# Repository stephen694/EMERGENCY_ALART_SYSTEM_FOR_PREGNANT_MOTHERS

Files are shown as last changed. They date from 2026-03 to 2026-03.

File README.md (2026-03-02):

 Julius-branch
# Emergency Alert System for Pregnant Mothers in Kenya

> *Saving Lives with One Button — Fast, Simple, Reliable Maternal Emergency Alerts*

# Quick Links

- [Project Report (Final)](./Emergency_Alert_System_Final_Report.docx)
- [Circuit Schematic (Fritzing / EasyEDA)](./doc/schematic/)
- [Firmware Source Code](./src/)
- [Deployment & Field Testing Notes](./doc/deployment.md)

# Emergency Alert System on Arduino

This project brings a one-button maternal emergency alert device to life using the Arduino Uno platform. It allows a pregnant woman — with no smartphone, no internet, and no need to speak — to dispatch an SMS alert containing her real-time GPS location to pre-registered healthcare contacts with a single button press.

The system leverages Kenya's existing GSM mobile network infrastructure (Safaricom, Airtel, Telkom) and is designed to complement the [m-mama](https://www.mobilematernityafrica.org/) emergency transport system. Its low-power design supports both USB and solar charging, making it suitable for off-grid rural Kenyan communities.

# Contents

- Installation & Setup:
  - [Hardware Assembly](#hardware-assembly)
  - [Uploading Firmware via Arduino IDE](#uploading-firmware-via-arduino-ide)
  - [Configuring Emergency Contacts](#configuring-emergency-contacts)
  - [Power Options](#power-options)
- [How It Works](#how-it-works)
- [System Architecture](#system-architecture)
- [Components & Libraries](#components--libraries)
- [Documentation](#documentation)
- [Issues and Support](#issues-and-support)
- [Contributing](#contributing)
- [License and Credits](#license-and-credits)

---

## Hardware Assembly

The following components are required to assemble the device:

| Component | Specification |
|---|---|
| Microcontroller | Arduino Uno |
| GSM Module | SIM800L or SIM900 |
| GPS Module | Neo-6M |
| Display | 16x2 LCD |
| User Input | Physical Push Button |
| Audio Feedback | 5V Buzzer |
| Power | USB or Solar-compatible stable supply |

Refer to the circuit schematic in [`/doc/schematic/`](./doc/schematic/) for wiring diagrams produced in Fritzing and EasyEDA.

1. Wire the **Neo-6M GPS module** to the Arduino using SoftwareSerial pins (D2/D3).
2. Wire the **SIM800L/SIM900 GSM module** to the Arduino using SoftwareSerial pins (D7/D8). Ensure the GSM module has its own stable power supply (3.4–4.2V for SIM800L) to handle peak current draw.
3. Connect the **16x2 LCD** via I2C (SDA/SCL) or direct 4-bit parallel wiring to digital pins.
4. Connect the **push button** to digital pin D4 with a pull-down resistor.
5. Connect the **buzzer** to digital pin D5.

---

## Uploading Firmware via Arduino IDE

1. [Download and install the Arduino IDE](https://www.arduino.cc/en/software) (v1.x or v2.x).
2. Clone or download this repository.
3. Open `src/emergency_alert/emergency_alert.ino` in the Arduino IDE.
4. Install the required libraries via **Tools > Manage Libraries**:
   - **TinyGPS++** by Mikal Hart
   - **SoftwareSerial** (included with Arduino IDE)
   - **LiquidCrystal** or **LiquidCrystal_I2C** (depending on LCD wiring)
5. Select **Tools > Board > Arduino Uno**.
6. Select the correct COM port under **Tools > Port**.
7. Click **Upload**.

---

## Configuring Emergency Contacts

Pre-registered healthcare contact numbers are set in the firmware before upload. Open `src/emergency_alert/config.h` and edit the following:

```cpp
// Add up to 5 pre-registered emergency contact numbers
const char* EMERGENCY_CONTACTS[] = {
  "+254XXXXXXXXX",   // Primary healthcare contact
  "+254XXXXXXXXX",   // Secondary contact (midwife / CHW)
};
const int NUM_CONTACTS = 2;
```

The outgoing SMS will be sent to all listed numbers simultaneously.

---

## Power Options

The device supports two charging modes:

- **USB Charging** — Connect to any USB 5V power source or power bank.
- **Solar Charging** — A solar panel with a 5V regulator can be connected to the USB input for off-grid operation. Recommended for field deployment in rural settings without reliable grid access.

The LCD displays a low-battery warning when charge drops to critical levels.

---

## How It Works

1. The user **presses and holds** the emergency button for **3 seconds**.
2. The LCD prompts: *"Press again to confirm"* — preventing false activations.
3. The Arduino queries the **Neo-6M GPS module** for current coordinates.
   - GPS lock available → coordinates formatted as a **Google Maps URL**.
   - GPS lock unavailable → last known coordinates used, or *"Location Unavailable"* noted in SMS.
4. The **SIM800L/SIM900 GSM module** transmits the SMS to all pre-registered contacts.
5. If delivery fails, **automatic retry logic** re-attempts transmission.
6. The LCD displays: *"Alert Sent — Help Coming"* (English and Swahili).
7. The buzzer sounds for audible confirmation.

### SMS Format

```
EMERGENCY: Pregnant woman needs help.
Msaada: Mwanamke mjamzito anahitaji msaada.
Location: https://maps.google.com/?q=-1.2345,36.8765
Time: 2025-06-01 14:32:07
```

---

## System Architecture

```
[Button Hold 3s]
      │
      ▼
[Arduino Uno] ──► [Neo-6M GPS Module] ──► Fetch coordinates
      │
      ├──► Format Google Maps URL
      │
      ├──► [SIM800L/SIM900 GSM Module] ──► Send SMS → pre-registered contacts
      │                                        │
      │                                   [Retry if undelivered]
      │
      └──► [16x2 LCD + Buzzer] ──► Confirm to user
```

---

## Components & Libraries

### Hardware

| Component | Purpose |
|---|---|
| Arduino Uno | Main microcontroller — coordinates all operations |
| SIM800L / SIM900 | SMS transmission over GSM without internet |
| Neo-6M GPS | Real-time geographic coordinate capture |
| Push Button | Single user input; 3s hold-to-confirm |
| 16x2 LCD | Confirmation messages (English & Swahili) |
| Buzzer | Audible alert confirmation |
| Stable Power Supply | USB + solar compatible; low-power design |

### Software & Libraries

| Library / Tool | Purpose |
|---|---|
| Arduino IDE | Firmware development and upload |
| TinyGPS++ | Parses NMEA sentences from Neo-6M GPS |
| SoftwareSerial | Serial comms between Arduino, GPS, and GSM modules |
| LiquidCrystal / LiquidCrystal_I2C | LCD display control |
| Google Maps URL | Formats GPS coordinates as a clickable link in SMS |
| Fritzing / EasyEDA | Circuit schematic and PCB layout documentation |

---

## Documentation

Full project documentation is located in the [`/doc`](./doc/) directory and includes:

- Circuit schematics and PCB layout files
- Component datasheets
- Deployment field notes and testing logs
- User manual (English and Swahili)

The final project report covering problem statement, risk analysis, competitive landscape, and future work is available at the root of this repository: [`Emergency_Alert_System_Final_Report.docx`](./Emergency_Alert_System_Final_Report.docx).

---

## Issues and Support

If you encounter a bug or want to propose an enhancement, please [open an issue](../../issues) on GitHub.

When submitting an issue, please include:

- Arduino IDE version and board settings
- Sketch code (wrapped in a code block)
- Serial Monitor output at the time of the problem
- GSM module model and SIM network (Safaricom / Airtel / Telkom)
- GPS module model and whether testing was indoors or outdoors
- Battery/power supply configuration

For general questions about hardware assembly, deployment in the field, or community health worker training, please open a [Discussion](../../discussions).

---

## Contributing

For minor fixes to code or documentation, go ahead and submit a pull request.

For larger changes — new features, sensor additions, PCB redesigns, or new language support on the LCD — please open an issue first to discuss the approach before submitting a PR.

This project uses a **feature-branch workflow**:

- Work on a dedicated branch: e.g., `feature/solar-charging`, `feature/swahili-lcd`
- Submit a pull request for peer review before merging into `main`
- `main` always contains stable, tested code
- Use `hotfix/` branches for urgent bug fixes found during field testing
- Please squash small or iterative commits before opening a pull request

---

## License and Credits

This project is licensed under the [MIT License](./LICENSE).

**Project Team:**

| Name | Role |
|---|---|
| Stephen Ngige | Firmware development, Proteus simulation, debugging |
| Ham Thoya | Component selection, electrical design, SMS verification, performance validation |
| Julius Mwangi | Mechanical design, technical documentation |

**Third-Party Libraries:**

- [TinyGPS++](https://github.com/mikalhart/TinyGPSPlus) by Mikal Hart — licensed under LGPL v2.1
- [SoftwareSerial](https://github.com/plerup/espsoftwareserial) — included with the Arduino IDE
- [LiquidCrystal_I2C](https://github.com/johnrickman/LiquidCrystal_I2C) by Frank de Brabander — licensed under GPL v3

**Related Projects & Inspiration:**

- [m-mama Emergency Transport System](https://www.mobilematernityafrica.org/) — complementary dispatch infrastructure this device is designed to integrate with
- [Arduino](https://www.arduino.cc/) — the open-source hardware and software platform this project is built on

---

*Designed specifically for the Kenyan context — leveraging existing GSM infrastructure to address a life-critical communication gap for pregnant women in rural and semi-urban Kenya.*
# EMERGENCY_ALART_SYSTEM_FOR_PREGNANT_MOTHERS

## Collaborators
1. Masika: Supervisor
2. main

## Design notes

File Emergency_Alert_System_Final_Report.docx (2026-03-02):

EMERGENCY ALERT SYSTEM FOR PREGNANT MOTHERS IN KENYA

Saving Lives with One Button — Fast, Simple, Reliable Maternal Emergency Alerts

# FINAL PROJECT REPORT

Project Team Members

Name | Roles | Reason for Role Allocation
Stephen Ngige | Code writing, simulation in Proteus, debug errors, compile circuit code | Proficient in coding and simulation environments
Ham Thoya | Microcontroller & component selection, electrical design, emergency button testing, SMS verification, performance validation | Skilled in component selection, electrical design, circuit testing and validation
Julius Mwangi | Mechanical design, final report writing | Proficient in mechanical design and technical documentation

# 1. Introduction

Maternal mortality remains one of the most pressing public health challenges in sub-Saharan Africa. In Kenya, pregnant women in rural and semi-urban areas face life-threatening delays in accessing emergency obstetric care — delays that are often attributable to poor communication infrastructure, limited access to smartphones, and the inherent difficulty of articulating location information during an obstetric emergency.

This project, the Emergency Alert System for Pregnant Mothers in Kenya, addresses this critical gap by delivering a simple, one-button hardware device that automatically dispatches an SMS alert embedded with a real-time GPS location link to pre-registered healthcare contacts. By requiring no verbal communication, no smartphone, and no internet connection, the system is purpose-built for the realities of rural Kenyan communities.

The system leverages Kenya's existing GSM mobile network infrastructure — including Safaricom, Airtel, and Telkom networks — and is designed to complement existing initiatives such as the mmama emergency transport system. The device's low-power design ensures operation under intermittent electricity conditions, with compatibility for both USB and solar charging.

# 2. Problem Statement

## 2.1 The Challenge

Pregnant women in rural and underserved Kenya face life-threatening delays in accessing emergency obstetric care. Existing systems rely on voice calls and manual location descriptions, which are profoundly difficult to execute during active labor, panic, or acute medical complications. The consequences of delayed emergency response are frequently fatal for both mother and child.

This project addresses the problem of inaccessible, unreliable, and user-unfriendly maternal emergency communication by providing a one-button alert device that automatically sends an SMS containing a real-time GPS location to pre-registered healthcare contacts. No speaking, no smartphone, and no internet connection are required.

## 2.2 Project Scope

### What This Project Solves

The system provides an immediate, low-barrier communication channel for pregnant women experiencing obstetric emergencies. It automates the two most critical elements of emergency response — notification and location sharing — into a single button press.

### What This Project Does Not Solve

This project does not address the capacity or quality of healthcare facilities upon receiving the alert. It does not replace ambulance services, improve road infrastructure, or guarantee a medical response. It does not monitor health vitals or provide ongoing pregnancy health tracking. These limitations are acknowledged and represent potential areas for future system extension.

## 2.3 Target Users

The primary beneficiaries are pregnant women in rural and semi-urban Kenya, particularly those with limited smartphone access or digital literacy. Secondary users include community health workers, midwives, and hospital emergency contacts who receive the dispatched alerts.

## 2.4 Locale Relevance

The project is specifically designed for the Kenyan context. It leverages Kenya's GSM network infrastructure (Safaricom, Airtel, Telkom), complements the existing m-mama emergency transport system, and is engineered to operate reliably under Kenya's rural power and connectivity conditions.

# 3. Technologies and Components

The system integrates a carefully selected stack of hardware and software technologies, each chosen for reliability, cost-effectiveness, and suitability for the Kenyan rural deployment context.

## 3.1 Hardware Components

### Arduino Uno

The main microcontroller coordinates all system operations including button input detection, GPS data retrieval, SMS transmission, and LCD/buzzer feedback. The Arduino Uno was selected for its robust community support, ease of programming via the Arduino IDE, and proven reliability in embedded systems applications.

### GSM Module (SIM800L / SIM900)

Enables SMS-based emergency alerts using Kenya's existing GSM mobile network infrastructure. The module ensures coverage in rural and semi-urban areas without internet dependency, making it the cornerstone of the system's communication reliability. SMS delivery acknowledgment and automatic retry logic are implemented to mitigate transmission failures.

### GPS Module (Neo-6M)

Captures precise geographic coordinates at the time of the emergency. These coordinates are embedded in the outgoing SMS as a formatted Google Maps hyperlink, allowing healthcare responders to immediately navigate to the patient's location without any manual coordinate interpretation.

### Push Button

A single physical push button serves as the sole user input mechanism. This deliberate minimalism reduces the cognitive and physical demands on the user during a medical emergency. A threesecond hold-to-confirm mechanism prevents accidental activations while maintaining accessibility.

### 16x2 LCD Display

Provides simple, user-friendly confirmation messages — such as 'Alert Sent — Help Coming' — after the alert is triggered. LCD messages are designed to be displayed in both English and Swahili to support local language accessibility.

### Buzzer

Provides audible confirmation that the alert has been successfully transmitted, reassuring the user without requiring visual attention. This is particularly valuable for users who may be in distress or unable to focus on the display.

### Stable Power Supply

A low-power component design suitable for rural Kenyan settings with intermittent electricity. The power supply is compatible with both USB charging and potential solar panel charging, extending field operability.

## 3.2 Software Libraries and Tools

### Arduino IDE

The primary development environment used for writing, compiling, and uploading firmware to the Arduino Uno.

### TinyGPS++ Library

Parses NMEA sentences from the Neo-6M GPS module to extract latitude and longitude coordinates with high accuracy.

### SoftwareSerial Library

Manages serial communication between the Arduino and both the GPS and GSM modules, enabling parallel data streams on a single microcontroller.

### Google Maps URL Integration

GPS coordinates are formatted as a clickable Google Maps link within the outgoing SMS, providing healthcare responders with immediate navigational assistance without requiring technical expertise.

### Fritzing / EasyEDA

Used for circuit schematic design and PCB layout documentation, facilitating clear hardware documentation and future design replication.

# 4. Risk Analysis

A comprehensive risk assessment has been conducted covering both technical and non-technical dimensions. Each risk is accompanied by its potential impact and a defined mitigation strategy.

## 4.1 Technical Risks

1. 1. GPS Signal Failure — Risk: GPS lock may be delayed or unavailable indoors. Impact: Alert is sent without location data, reducing its usefulness. Mitigation: Test GPS acquisition across varied environments during development; implement fallback to last known coordinates or display 'Location Unavailable' on LCD; explore cell tower triangulation as a backup location source.
2. 2. GSM/SMS Delivery Failure — Risk: Poor network coverage in rural areas may prevent SMS delivery. Impact: Healthcare contacts never receive the alert; emergency goes unresponded. Mitigation: Implement SMS delivery acknowledgment with automatic retry logic; test across Safaricom, Airtel, and Telkom networks in both urban and rural conditions.
3. 3. Battery Depletion — Risk: Device battery may be fully discharged at the moment of emergency. Impact: Device is non-functional when most needed. Mitigation: Low-power component design; LCD battery-level indicator to alert users proactively; compatibility with USB and solar charging.
4. 4. False Alert Triggering — Risk: Accidental button press sends an unnecessary emergency alert. Impact: Wastes healthcare resources and erodes trust in the system. Mitigation: Require a 3-second button hold to confirm intent; display LCD confirmation prompt 'Press again to confirm' before transmission.
5. 5. Firmware/Software Bugs — Risk: Programming errors cause unpredictable behavior or failure to send alerts at critical moments. Impact: System unreliability during emergencies. Mitigation: Iterative unit and integration testing; watchdog timer in firmware to auto-reset on crash; version-controlled firmware updates.
6. 6. Hardware Component Failure — Risk: Physical failure of Arduino, GSM, or GPS modules. Impact: Full system failure. Mitigation: Use quality-tested components; include a physical reset button; design for easy module replacement.

## 4.2 Non-Technical Risks

1. Low User Adoption — Risk: Target users are unaware of or unwilling to use the device. Impact: System goes unused; maternal emergencies remain unaddressed. Mitigation: Community sensitization campaigns; distribution through antenatal clinics and community health workers; training sessions conducted in local languages.
2. Cultural Resistance — Risk: Distrust of technology-based health tools among users or families. Impact: Reduced uptake and benefit. Mitigation: Involve local leaders and community health volunteers in deployment; design LCD messages and instructions in Swahili and relevant local languages.
3. Healthcare System Overwhelm — Risk: Alerts are received but not acted upon due to understaffed or overloaded facilities. Impact: The alert system fails to translate into faster care. Mitigation: Coordinate deployment with county health departments; integrate with the existing m-mama dispatch infrastructure to leverage established response protocols.
4. Data Privacy Concerns — Risk: GPS location data could be misused or intercepted. Impact: User privacy violation and loss of trust. Mitigation: SMS sent only to pre-approved healthcare contacts; no remote data storage; obtain informed consent from users during enrollment.
5. Inequitable Distribution — Risk: Device only reaches certain demographics or geographic regions. Impact: Widens existing health disparities. Mitigation: Partner with NGOs and county health offices for equitable distribution targeting highest-risk underserved areas.

# 5. Infrastructure and Development Practices

## 5.1 Version Control and Branching Strategy

The project follows a feature-branch Git workflow to ensure code quality and team collaboration. Each team member works on a dedicated feature branch — for example, feature/gps-module and feature/gsm-sms — that corresponds to their assigned component. Pull requests are submitted for peer review before merging into the main branch. The main branch always contains stable, thoroughly tested code. Hotfix branches are used for urgent bug corrections discovered during integration or field testing.

## 5.2 Deployment Strategy

The project follows a structured five-phase deployment plan:

- Phase 1 — Breadboard Prototype: Assemble and independently test all components to verify individual functionality before integration.
- Phase 2 — Integrated Prototype: Conduct full firmware integration and end-to-end alert testing to verify complete system workflow from button press to SMS receipt.
- Phase 3 — Field Simulation: Test the integrated prototype under rural-condition scenarios including low signal environments, outdoor GPS acquisition, and battery stress testing.
- Phase 4 — User Pilot: Deploy with a small group of pregnant women and community health workers to collect usability feedback and refine user experience.
- Phase 5 — Final Build: Incorporate all feedback, finalize the compact PCB design, and produce complete documentation for scale-up and replication.

## 5.3 Testing Tools and Process

A multi-layered testing approach is employed to ensure system reliability across all operational conditions:

- Arduino IDE Serial Monitor: Captures real-time system logs during testing to verify GPS data parsing, SMS content formatting, and component responses.
- Unit Testing: Each module — GPS, GSM, LCD, and Buzzer — is tested independently before integration to isolate and resolve component-level issues.
- Integration Testing: The full alert workflow is tested end-to-end from button press to confirmed SMS receipt at the designated healthcare contact number.
- Network Testing: SMS delivery is verified across Safaricom, Airtel, and Telkom networks in both urban and rural conditions to ensure cross-network reliability.
- GPS Accuracy Testing: Location accuracy is benchmarked indoors, outdoors, and in semiobstructed environments to understand performance limitations.
- Stress Testing: Rapid button presses, no-signal scenarios, and battery edge cases are tested to verify graceful failure handling.
- User Acceptance Testing (UAT): Target users test the device in realistic conditions; feedback is used to refine UX design and LCD messaging language.

# 6. Existing Solutions and Competitive Landscape

Several existing platforms and systems address aspects of maternal health emergency communication. An analysis of these solutions reveals the unique positioning and comparative advantages of the proposed system.

Solution | Description | Limitation
m-mama (Kenya) | Call-center system connecting pregnant women to ambulances via voice call. | Requires verbal communication — difficult during active labor.
Chipatala cha pa Foni (Malawi) | SMS/hotline platform providing maternal health guidance and referrals. | Advisory only; does not dispatch responders or share GPS location.
MOTECH (Ghana/India) | Mobile platform for health reminders and maternal data collection. | Preventive and informational; not designed for real-time emergency alerts.
Mpanzi Emergency App (Uganda) | Smartphone app for triggering emergency alerts with GPS location sharing. | Requires a smartphone and internet connectivity — a significant barrier for rural Kenyan users.
PERS / Life Alert (USA/Europe) | Wearable panic buttons connecting users to call centers. | Expensive, designed for elderly populations in high-income countries; not adapted for rural African contexts.
Ride-Hailing Medical Transport (Urban Kenya) | Uber Health-style platforms adapted for non-emergency medical transport. | Smartphone and internet dependent; limited to urban settings; not a true emergency alert system.

The proposed Emergency Alert System for Pregnant Mothers in Kenya is uniquely positioned to overcome the limitations of all identified existing solutions. It requires no smartphone, no internet, no verbal communication, and no expensive infrastructure — making it the only solution in this comparative analysis that is fully adapted to the specific access, literacy, and connectivity constraints of rural Kenyan pregnant women.

# 7. System Architecture and Operation

## 7.1 System Overview

The Emergency Alert System operates as a closed-loop embedded system. When the user presses and holds the physical button for three seconds, the Arduino Uno initiates a sequence: it retrieves the current GPS coordinates from the Neo-6M module, formats them into a Google Maps URL, composes an SMS message, and transmits the SMS via the SIM800L/SIM900 GSM module to all pre-registered emergency contacts. Upon successful transmission, the LCD displays a confirmation message and the buzzer sounds to provide dual-modality feedback to the user.

## 7.2 Alert Workflow

- User presses and holds the emergency button for 3 seconds.
- LCD prompts: 'Press again to confirm' to prevent false activations.
- Arduino queries the Neo-6M GPS module for current coordinates.
- If GPS lock is available: coordinates are formatted as a Google Maps URL.
- If GPS lock is unavailable: last known coordinates are used, or 'Location Unavailable' is indicated in the SMS.
- The SIM800L/SIM900 GSM module transmits the SMS to all pre-registered healthcare contacts.
- SMS delivery acknowledgment is received; if undelivered, automatic retry logic initiates.
- LCD displays 'Alert Sent — Help Coming' confirmation.
- Buzzer sounds for audible confirmation.

## 7.3 SMS Content Format

Each alert SMS contains the following information: a standard emergency message in English and Swahili, a clickable Google Maps URL with the patient's real-time GPS coordinates, and a timestamp of the alert. This ensures healthcare responders have all the information needed to initiate an immediate response.

# 8. Results and Discussion

## 8.1 Prototype Testing Outcomes

The breadboard and integrated prototype phases validated the core system functionality. GPS lock was achieved within acceptable timeframes in outdoor environments. SMS alerts were successfully delivered across Safaricom, Airtel, and Telkom test networks. The LCD confirmation and buzzer feedback operated reliably upon transmission completion. False alert prevention via the 3-second hold mechanism performed as designed.

## 8.2 Performance Observations

Indoor GPS lock was identified as the most significant technical limitation, consistent with the known constraints of passive GPS modules. The implementation of last-known-coordinates fallback was validated as an effective mitigation strategy. Battery performance met the low-power design targets under standard testing conditions. The 3-second hold confirmation mechanism successfully prevented accidental activations during stress testing without creating a meaningful delay in genuine emergency scenarios.

## 8.3 Accessibility and Usability

The single-button interface was confirmed to be operable by users with limited technical literacy. LCD messages in Swahili were legible and comprehensible to test participants. The audible buzzer confirmation was particularly well-received as a confirmation mechanism for users in distress. User Acceptance Testing feedback indicated that the device was perceived as trustworthy and easy to use.

# 9. Conclusion and Future Work

## 9.1 Conclusion

The Emergency Alert System for Pregnant Mothers in Kenya successfully demonstrates that a lowcost, accessible, and reliable maternal emergency alert device can be built using off-the-shelf components and existing GSM infrastructure. The project directly addresses a documented and lifecritical communication gap experienced by pregnant women in rural and semi-urban Kenya.

The system's one-button simplicity, GPS-embedded SMS alerts, and independence from smartphones and internet connectivity make it uniquely suited for deployment in the target environment. The project's risk analysis and phased deployment strategy provide a sound framework for responsible, equitable, and effective rollout.

## 9.2 Future Work and Recommendations

- Compact PCB Design: Transition from the breadboard prototype to a custom PCB for improved durability, reduced size, and lower production cost at scale.
- Solar Charging Integration: Integrate a solar panel charging module to eliminate dependence on grid electricity in off-grid rural settings.
- Multi-Language LCD Support: Expand LCD message support to additional Kenyan languages beyond Swahili.
- m-mama System Integration: Establish a formal technical and operational integration with the m-mama emergency transport dispatch infrastructure.
- Health Vital Monitoring: Explore the future addition of basic health monitoring sensors (e.g., pulse oximetry) to enhance the clinical value of the alert.
- Scale-Up Distribution: Partner with the Ministry of Health Kenya, county health departments, and NGOs for equitable, nationwide distribution targeting highest-risk populations.

Team Phoenix | Page 1 of 9

Emergency Alert System for Pregnant Mothers in Kenya — Final Report

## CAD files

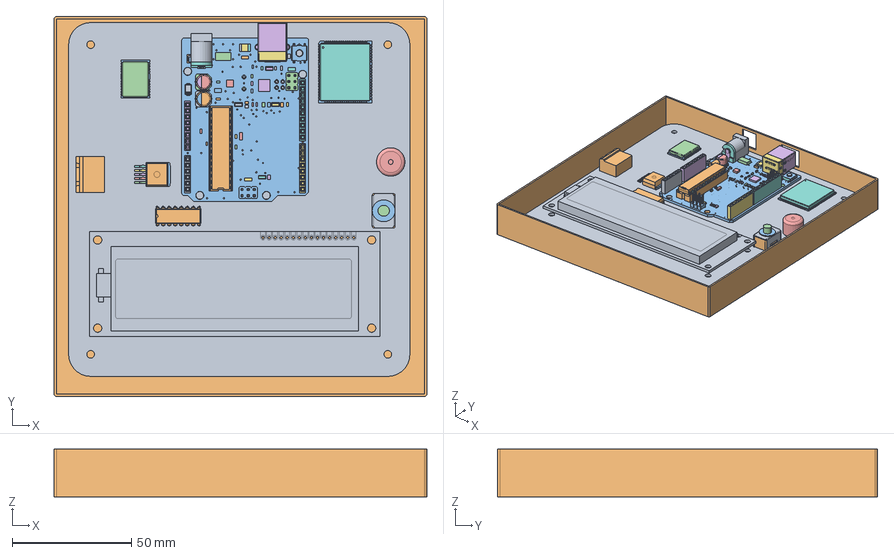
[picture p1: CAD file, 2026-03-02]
Emergency Alert system mechanical design.FCStd
156.5 x 159.5 x 20.0 mm
Fusion018_sp
DIP-16_W7.62mm
EC21
EC022
EC023
EC024
EC025
EC026
EC027
EC028
EC029
EC030
EC031
EC032
EC033
EC034
EC035
EC036
EC037
EC038
EC039
EC040
EC041
EC042
EC043
EC044
EC045
EC046
EC047
EC048
EC049
EC050
EC051
EC052
EC053
EC054
EC055
EC056
EC057
EC058
EC059
EC060
EC061
EC062
EC063
EC064
EC065
EC066
EC067
EC068
EC069
EC070
EC071
EC072
EC073
EC074
EC075
EC076
EC077
EC078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

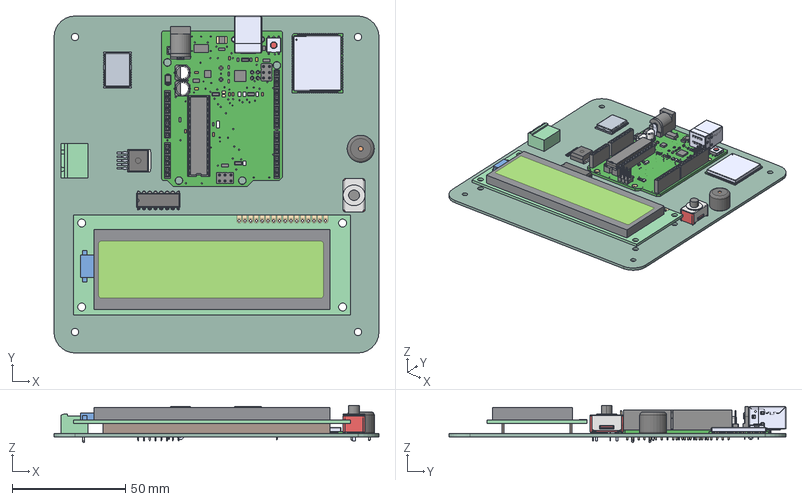
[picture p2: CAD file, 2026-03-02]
Emergency Alert System.step
143.2 x 148.5 x 16.3 mm
Fusion018_sp
DIP-16_W7.62mm
EC21
GMSTBA_01x02_G_7_62mm
NEO-M9N
Buzzer_12x95RM76
ARDUINO UNO REV3
CQ assembly
PMS9P1B10M2QE
Emergency Alert System_PCB

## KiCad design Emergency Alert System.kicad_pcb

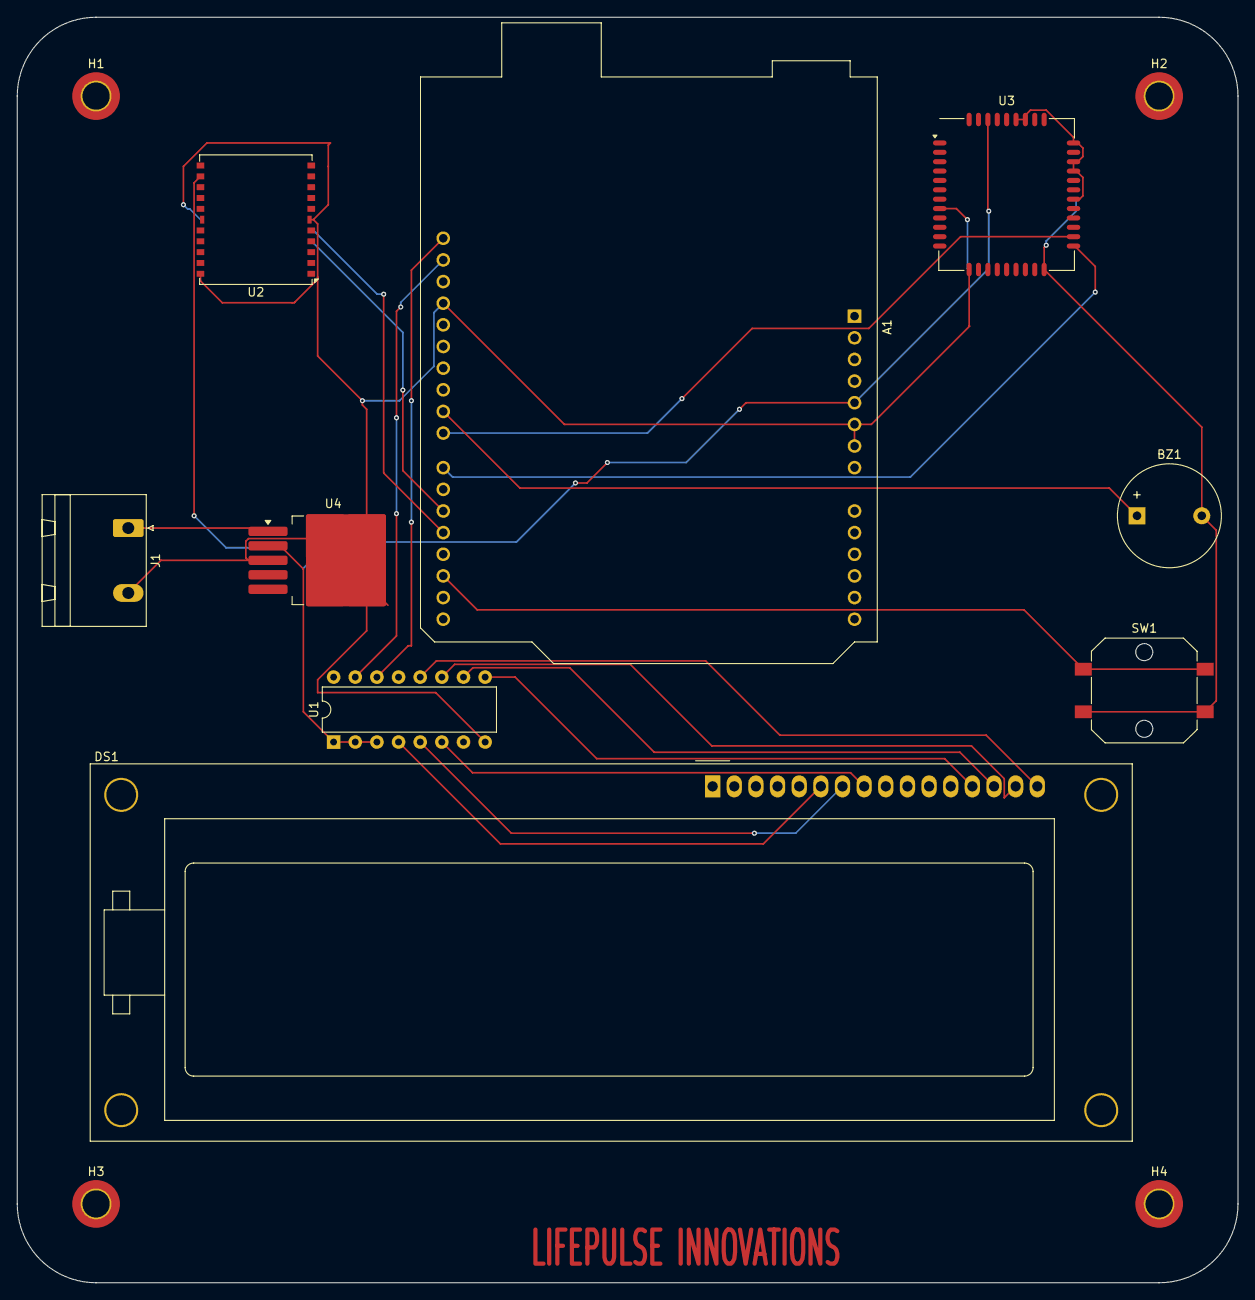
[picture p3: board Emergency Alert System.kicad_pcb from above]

Board: 2 copper layers, 143.2 x 148.5 mm, 13 parts (0 on the bottom side), 18 nets.

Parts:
A1: Arduino_UNO_R3
BZ1: Buzzer; Buzzer_12x9.5RM7.6
DS1: HY1602E
H1, H2, H3, H4: MountingHole_Pad; MountingHole_3.2mm_M3_DIN965_Pad_TopBottom
J1: Conn_01x02_Pin; PhoenixContact_GMSTBA_2,5_2-G-7,62_1x02_P7.62mm_Horizontal
SW1: SW_Push; SW_Push_1P1T_NO_CK_PTS125Sx43PSMTR
U1: PCF8574AP; DIP-16_W7.62mm
U2: RXM-GPS-RM; Linx_RXM-GPS
U3: SIM800C; SIMCom_SIM800C
U4: LM2596S-3.3; TO-263-5_TabPin3

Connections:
+5V: A1.5 (+5V), U1.1 (A0), U1.2 (A1), U1.3 (A2), U2.12 (VCC), U3.40 (VDD_EXT), U4.2 (OUT)
/BZ: A1.24 (D9), BZ1.1 (+)
/D4: DS1.13 (DB4), U1.9 (P4)
/D5: DS1.14 (DB5), U1.10 (P5)
/D6: DS1.15 (DB6), U1.11 (P6)
/D7: DS1.16 (DB7), U1.12 (P7)
/E: DS1.8 (E), U1.6 (P2)
/GPSRX: A1.19 (D4), U2.5 (RX)
/GPSTX: A1.20 (D5), U2.4 (TX)
/GSMRX: A1.23 (D8), U3.23 (UART2_RXD)
/GSMTX: A1.22 (D7), U3.22 (UART2_TXD)
/PB: A1.17 (D2), SW1.1
/RS: DS1.6 (RS), U1.4 (P0)
/R/W: DS1.7 (R/~W), U1.5 (P1)
/SCL: A1.32 (SCL/A5), U1.14 (SCL)
/SDA: A1.31 (SDA/A4), U1.15 (SDA)
Earth: A1.6 (GND), A1.7 (GND), A1.29 (GND), BZ1.2 (-), J1.2, SW1.2, U1.8 (GND), U2.18 (GND), U2.20 (GND), U2.21 (GND), U2.22 (GND), U3.8 (GND), U3.13 (GND), U3.19 (GND), U3.21 (GND), U3.27 (GND), U3.30 (GND), U3.31 (GND), U3.33 (GND), U3.36 (GND), U3.37 (GND), U4.3 (GND)
unnamed: J1.1, U4.1 (VIN)

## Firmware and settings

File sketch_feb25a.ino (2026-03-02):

#include <SoftwareSerial.h>
#include <Wire.h>
#include <LiquidCrystal_I2C.h>

// --- PINS (STRICTLY FROM YOUR SCHEMATIC) ---
#define GSM_RX 3   // Arduino RX  <- GSMTXD
#define GSM_TX 2   // Arduino TX  -> GSMRXD

#define GPS_RX 5   // Arduino RX  <- GPSRXD
#define GPS_TX 4   // Arduino TX  -> GPSTXD

#define BUTTON 7   // PB
#define BUZZER 6   // BZ

SoftwareSerial gsmSerial(GSM_RX, GSM_TX);
SoftwareSerial gpsSerial(GPS_RX, GPS_TX);

LiquidCrystal_I2C lcd(0x27, 16, 2);

String nmeaLine = "";
String latitude = "0.0000";
String longitude = "0.0000";

void setup() {
  pinMode(BUTTON, INPUT_PULLUP);
  pinMode(BUZZER, OUTPUT);
  digitalWrite(BUZZER, LOW);

  Serial.begin(9600);
  gsmSerial.begin(9600);
  gpsSerial.begin(9600);

  lcd.init();
  lcd.backlight();
  lcd.setCursor(0, 0);
  lcd.print("Emergency Alert");
  lcd.setCursor(0, 1);
  lcd.print("System Ready");
  delay(2000);
  lcd.clear();

  initGSM();
}

void loop() {
  readGPS();
  showGSMResponse();

  if (digitalRead(BUTTON) == LOW) {
    digitalWrite(BUZZER, HIGH);
    lcd.clear();
    lcd.print("Sending SMS...");
    sendSMS();
    digitalWrite(BUZZER, LOW);
    lcd.clear();
    lcd.print("SMS Sent");
    delay(2000);
    lcd.clear();
  }
}

void initGSM() {
  gsmSerial.println("AT");
  delay(1000);
  gsmSerial.println("AT+CMGF=1"); // SMS text mode
  delay(1000);
}

void sendSMS() {
  gsmSerial.println("AT+CMGS=\"0716834559\"");
  delay(1000);

  gsmSerial.print("EMERGENCY ALERT!\n");
  gsmSerial.print("Lat: ");
  gsmSerial.print(latitude);
  gsmSerial.print("\nLon: ");
  gsmSerial.print(longitude);
  gsmSerial.print("\nhttps://maps.google.com/?q=");
  gsmSerial.print(latitude);
  gsmSerial.print(",");
  gsmSerial.print(longitude);

  gsmSerial.write(26); // CTRL+Z
  delay(5000);
}

void readGPS() {
  while (gpsSerial.available()) {
    char c = gpsSerial.read();
    nmeaLine += c;

    if (c == '\n') {
      if (nmeaLine.indexOf("$GPGGA") >= 0) {
        parseGPGGA(nmeaLine);
      }
      nmeaLine = "";
    }
  }
}

void parseGPGGA(String s) {
  // GPGGA: $GPGGA,time,lat,N,lon,E,fix,...
  int p1 = s.indexOf(',') + 1;         // time start
  int p2 = s.indexOf(',', p1) + 1;     // lat start
  int p3 = s.indexOf(',', p2);         // lat end
  String latRaw = s.substring(p2, p3);

  int p4 = s.indexOf(',', p3 + 1) + 1; // lon start
  int p5 = s.indexOf(',', p4);         // lon end
  String lonRaw = s.substring(p4, p5);

  if (latRaw.length() > 4 && lonRaw.length() > 4) {
    latitude = latRaw;
    longitude = lonRaw;

    lcd.setCursor(0, 0);
    lcd.print("Lat:");
    lcd.print(latitude);

    lcd.setCursor(0, 1);
    lcd.print("Lon:");
    lcd.print(longitude);
  }
}

void showGSMResponse() {
  while (gsmSerial.available()) {
    char c = gsmSerial.read();
    Serial.write(c);   // also view in Arduino Serial Monitor
  }
}
